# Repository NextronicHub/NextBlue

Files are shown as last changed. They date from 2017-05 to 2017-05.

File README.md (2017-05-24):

# Nextronic NextBlue

With nextBlue, your Iot and Bluetooth applications are  easier to make
it's a 5v 16Mhz board based on the ATmega328P microcontroller with a built-in Bluetooth connector
NextBlue can be programmed over a USB Mini-B cable using the Arduino IDE: Just plug in the board, select “Arduino UNO” from the board menu and you’re ready to upload code.
NextBlue has all of the hardware peripherals like the Arduino.

## Features

  ATmega328 microcontroller with Optiboot (UNO) Bootloader<br />
  Input voltage - 7-15V<br />
  0-5V outputs<br />
  14 Digital I/O Pins (6 PWM outputs)<br />
  6 Analog Inputs<br />
  I2C, UART and SPI<br />
  32k Flash Memory<br />
  16MHz Clock Speed<br />
  All SMD Construction<br />
  R3 Shield Compatible<br />
  Bluetooth connector (EN, 5V, GND, TX, RX, STATE) <br />
  Software/hardware serial selector switch for the Bluetooth<br />

<br />
<br />
[FTDI driver](http://www.ftdichip.com/Drivers/VCP.htm)

Nextronic Product page:[NextBlue](http://nextronic.ma/product/nextblue/).

you can by it at: [makershop.ma](http://makershop.ma/).

## Repository Contents

/Hardware - Design files (.brd, .sch)  
/Firmware - bootloader  
/Documentation - datasheet and examples

## Product Versions

NextBlue_V1 first release

## License Information

The hardware is released under [Creative Commons ShareAlike 4.0 International](https://creativecommons.org/licenses/by-sa/4.0/).

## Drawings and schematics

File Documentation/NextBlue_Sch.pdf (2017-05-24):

# GND 0.1uF

# LED3 J5

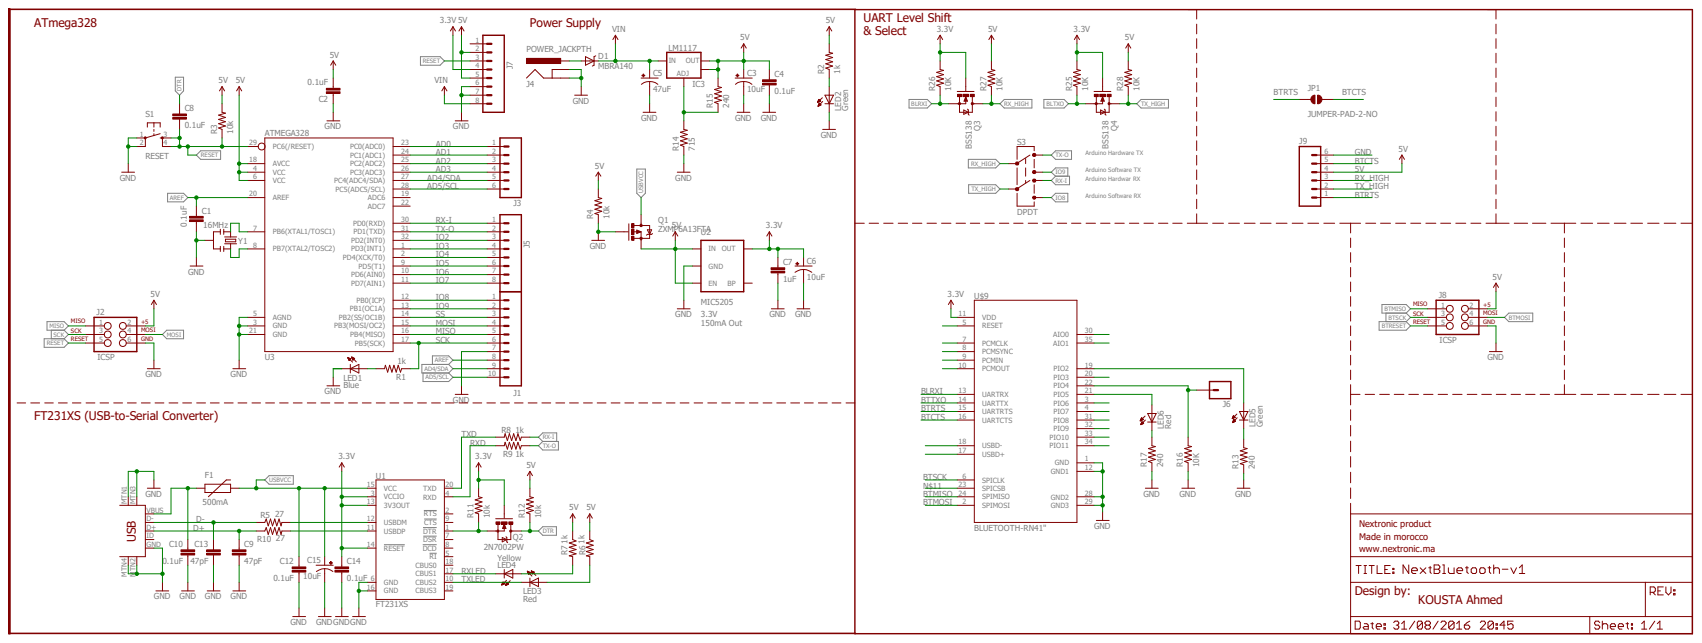
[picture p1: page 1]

FT231XS (USB-to-Serial Converter)

ID MTN¹ MTN³ MTN⁴ MTN²
GND

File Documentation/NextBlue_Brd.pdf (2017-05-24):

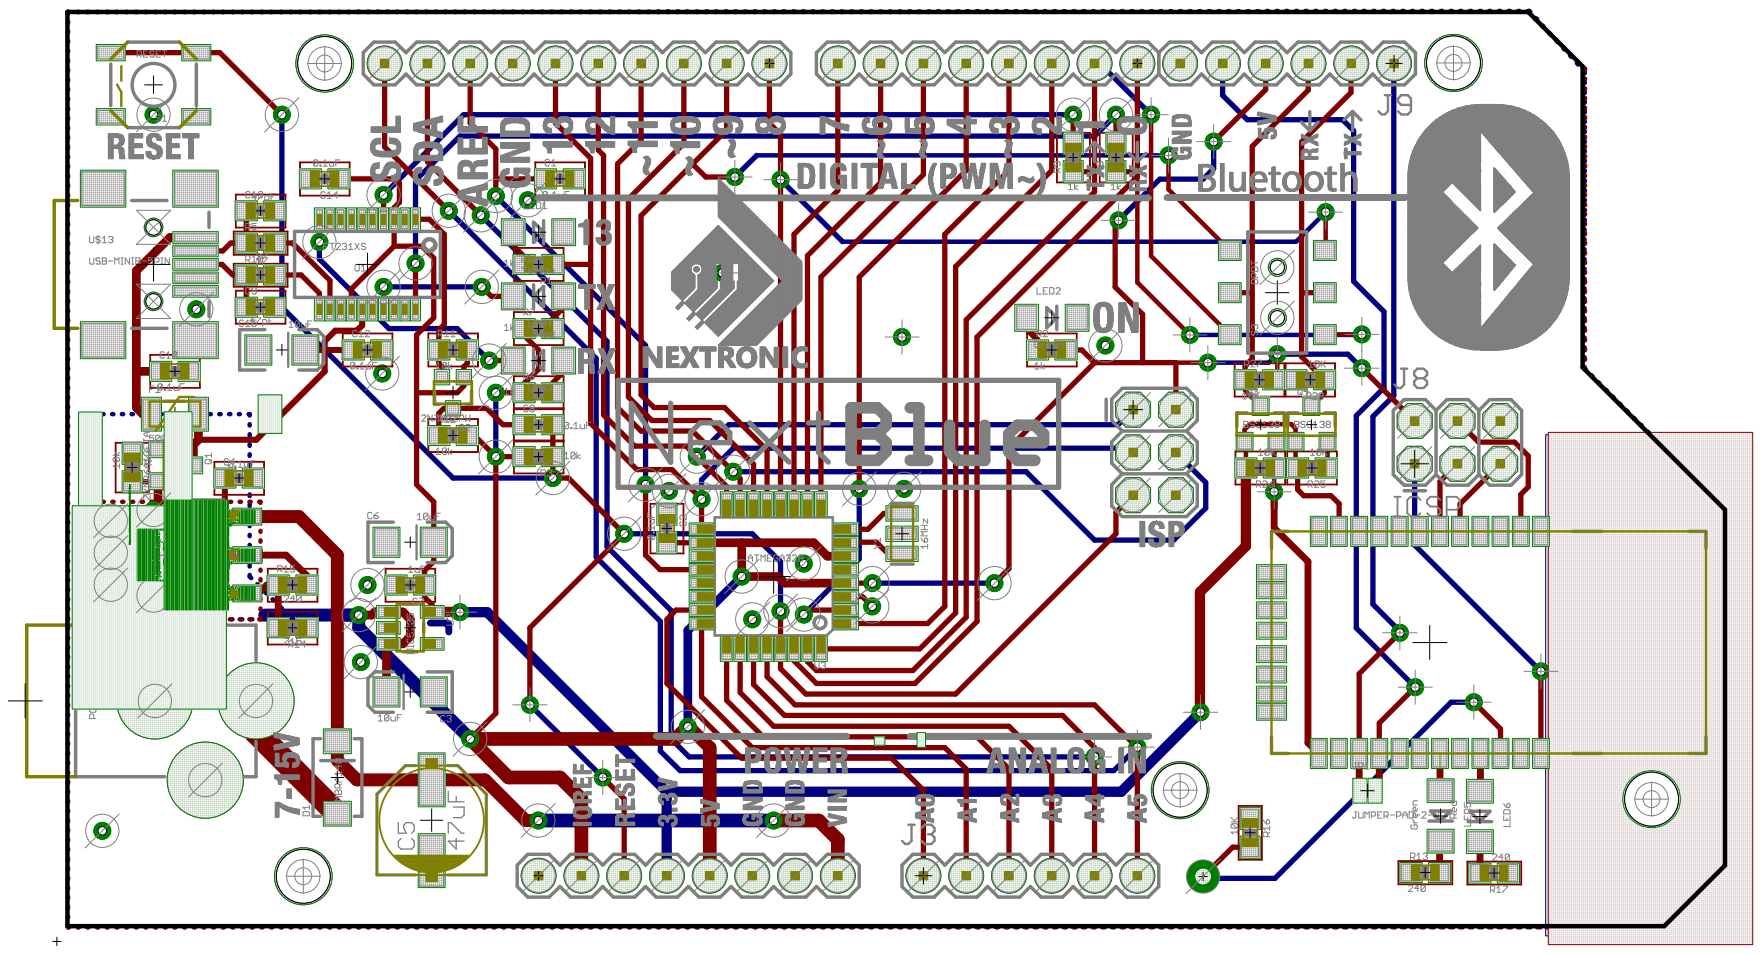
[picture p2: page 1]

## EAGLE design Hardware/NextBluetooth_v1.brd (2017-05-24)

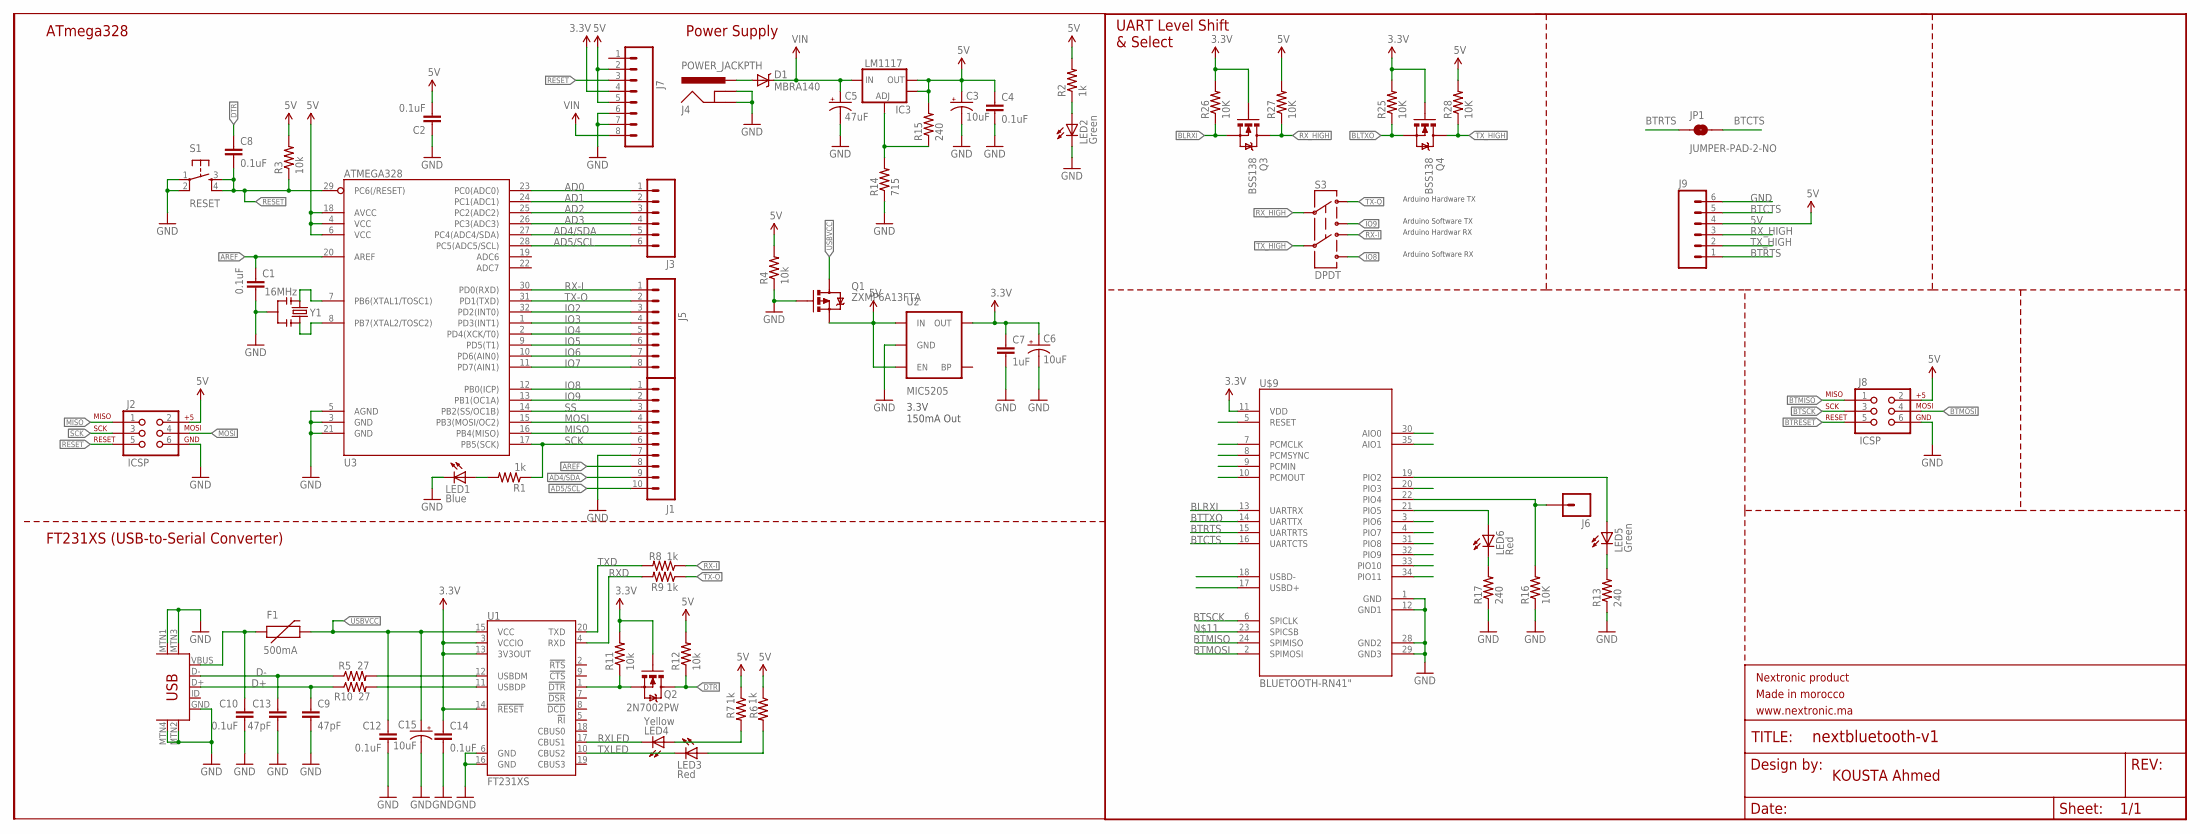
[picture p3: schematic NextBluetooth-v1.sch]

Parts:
C1, C2, C4, C8, C10, C12, C14: 0.1uF; 0603-CAP; MPN 0805B104K500CT
C3, C6, C15: 10uF; EIA3216; MPN MCSH21B104K101CT
C5: 47uF; PANASONIC_D; MPN EEEFT1H470AP
C7: 1uF; 0603-CAP; MPN ECA2GHG2R2
C9, C13: 47pF; 0603-CAP@1; MPN 08051A470JAT2A
D1: MBRA140; SMA-DIODE; MPN B140-13-F
F1: 500mA; PTC-1206; MPN 1N4148.
FRAME1: FRAME-LETTER; CREATIVE_COMMONS
IC3: LM1117; SOT223-ALT1; MPN LD1117S33TR
J1: M10SILK_FEMALE_PTH; 1X10
J2, J8: ICSP; 2X3
J3, J9: M06SILK_FEMALE_PTH; 1X06
J4: POWER_JACKPTH; POWER_JACK_PTH
J5, J7: M08; 1X08_ROUND
J6: M01NOSILK-KIT; 1X01NS-KIT
JP1: JUMPER-PAD-2-NO; PAD-JUMPER-2-NO_NO_SILK
LED1: Blue; LED-1206-NO_SILK; MPN 703-1028
LED2, LED5: Green; LED-1206-NO_SILK; MPN 703-1028
LED3, LED6: Red; LED-1206-NO_SILK; MPN 703-1028
LED4: Yellow; LED-1206-NO_SILK; MPN TLUY2401
Q1: ZXMP6A13FTA; SOT23-3; MPN ZXMP6A13FTA
Q2: 2N7002PW; SOT323; MPN 2N7002PW
Q3, Q4: BSS138; SOT23-3; MPN BSS138PW
R1, R2, R6, R7, R8, R9: 1k; 0603-RES; MPN ERA6AEB102V
R3, R4, R11, R12: 10k; 0603-RES; MPN MC0063W0603510K
R5, R10: 27; 0603-RES; MPN 22-27-2021
R13, R15, R17: 240; 0603-RES; MPN MCMR06X2200FTL
R14: 715; 0603-RES; MPN RC0603JR-07150RL
R16: 10K; 0603-RES; MPN RR0816P-103-B-T5
R25, R26, R27, R28: 10K; 0603-RES@2; MPN RR0816P-103-B-T5
S1: RESET; TACTILE_SWITCH_SMD
S3: DPDT; AYZ0202
U1: FT231XS; SSOP20_L; MPN FT231XS
U2: MIC5205; SOT23-5; MPN MIC5205-5.0YM5 TR
U3: ATMEGA328; TQFP32-08; MPN ATMEGA328P-AN
U$9: BLUETOOTH-RN41"; RN41
U$13: USB-MINIB-5PIN; USB-MINIB
Y1: 16MHz; RESONATOR-SMD

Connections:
3.3V: C6.A (+), C7.1, C14.1, J7.4, Q2.1 (G), Q3.1 (G), Q4.1 (G), R11.2, R25.2, R26.2, U1.3 (VCCIO), U1.13 (3V3OUT), U1.14 (!RESET), U2.5 (OUT), U$9.11 (VDD)
5V: C2.2, C3.A (+), C4.1, IC3.2 (OUT), IC3.4 (OUT), J2.2, J7.2, J7.5, J8.2, J9.4, Q1.2 (S), R2.2, R3.2, R4.2, R6.1, R7.1, R12.2, R15.2, R27.2, R28.2, U2.1 (IN), U2.3 (EN), U3.4 (VCC), U3.6 (VCC), U3.18 (AVCC)
AD0: J3.1, U3.23 (PC0(ADC0))
AD1: J3.2, U3.24 (PC1(ADC1))
AD2: J3.3, U3.25 (PC2(ADC2))
AD3: J3.4, U3.26 (PC3(ADC3))
AD4/SDA: J1.9, J3.5, U3.27 (PC4(ADC4/SDA))
AD5/SCL: J1.10, J3.6, U3.28 (PC5(ADC5/SCL))
AREF: C1.1, J1.8, U3.20 (AREF)
BLRXI: Q3.2 (S), R26.1, U$9.13 (UARTRX)
BLTXO: Q4.2 (S), R25.1
BTCTS: J9.5, JP1.2, U$9.16 (UARTCTS)
BTMISO: J8.1, U$9.24 (SPIMISO)
BTMOSI: J8.4, U$9.2 (SPIMOSI)
BTRESET: J8.5, U$9.5 (RESET)
BTRTS: J9.1, JP1.1, U$9.15 (UARTRTS)
BTSCK: J8.3, U$9.6 (SPICLK)
BTTXO: U$9.14 (UARTTX)
D+: C9.1, R10.1, U$13.D+
D-: C13.1, R5.1, U$13.D-
DTR: C8.1, Q2.3 (D), R12.1
GND: C1.2, C2.1, C3.C (-), C4.2, C5.-, C6.C (-), C7.2, C9.2, C10.2, C12.2, C13.2, C14.2, C15.C (-), J1.7, J2.6, J4.GND, J4.GNDBREAK, J7.6, J7.7, J8.6, J9.6, LED1.C, LED2.C, Q1.1 (G), R4.1, R13.1, R14.1, R16.1, R17.1, S1.1, S1.2, U1.6 (GND), U1.16 (GND), U2.2 (GND), U3.3 (GND), U3.5 (AGND), U3.21 (GND), U$9.1 (GND), U$9.12 (GND1), U$9.28 (GND2), U$9.29 (GND3), U$13.GND, U$13.MTN1 (MTN2), U$13.MTN2 (MTN3), U$13.MTN3 (MTN1), U$13.MTN4, Y1.2
IO2: J5.3, U3.32 (PD2(INT0))
IO3: J5.4, U3.1 (PD3(INT1))
IO4: J5.5, U3.2 (PD4(XCK/T0))
IO5: J5.6, U3.9 (PD5(T1))
IO6: J5.7, U3.10 (PD6(AIN0))
IO7: J5.8, U3.11 (PD7(AIN1))
IO8: J1.1, S3.6, U3.12 (PB0(ICP))
IO9: J1.2, S3.3, U3.13 (PB1(OC1A))
MISO: J1.5, J2.1, U3.16 (PB4(MISO))
MOSI: J1.4, J2.4, U3.15 (PB3(MOSI/OC2))
unnamed: LED1.A, R1.2
unnamed: LED2.A, R2.1
unnamed: U3.7 (PB6(XTAL1/TOSC1)), Y1.1
unnamed: U3.8 (PB7(XTAL2/TOSC2)), Y1.3
unnamed: D1.A, J4.PWR
unnamed: R5.2, U1.12 (USBDM)
unnamed: R10.2, U1.11 (USBDP)
unnamed: LED3.A, R6.2
unnamed: LED4.A, R7.2
unnamed: Q2.2 (S), R11.1, U1.1 (!DTR)
unnamed: IC3.1 (ADJ), R14.2, R15.1
unnamed: LED6.A, U$9.21 (PIO5)
unnamed: J6.1, R16.2, U$9.22 (PIO4)
unnamed: LED5.A, U$9.19 (PIO2)
unnamed: LED5.C, R13.2
unnamed: LED6.C, R17.2
RESET: C8.2, J2.5, J7.3, R3.1, S1.3, S1.4, U3.29 (PC6(/RESET))
RX-I: J5.1, R8.1, S3.4, U3.30 (PD0(RXD))
RXD: R9.2, U1.4 (RXD)
RXLED: LED4.C, U1.17 (CBUS1)
RX_HIGH: J9.3, Q3.3 (D), R27.1, S3.2
SCK: J1.6, J2.3, R1.1, U3.17 (PB5(SCK))
SS: J1.3, U3.14 (PB2(SS/OC1B))
TX-O: J5.2, R9.1, S3.1, U3.31 (PD1(TXD))
TXD: R8.2, U1.20 (TXD)
TXLED: LED3.C, U1.10 (CBUS2)
TX_HIGH: J9.2, Q4.3 (D), R28.1, S3.5
USBVCC: C12.1, C15.A (+), F1.2, Q1.3 (D), U1.15 (VCC)
VIN: C5.+, D1.C, IC3.3 (IN), J7.8
VUSB: C10.1, F1.1, U$13.VBUS

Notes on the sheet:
Power Supply
ATmega328
FT231XS (USB-to-Serial Converter)
3.3V 150mA Out
KOUSTA Ahmed
UART Level Shift & Select
Arduino Software TX
Arduino Software RX
Arduino Hardwar RX
Arduino Hardware TX

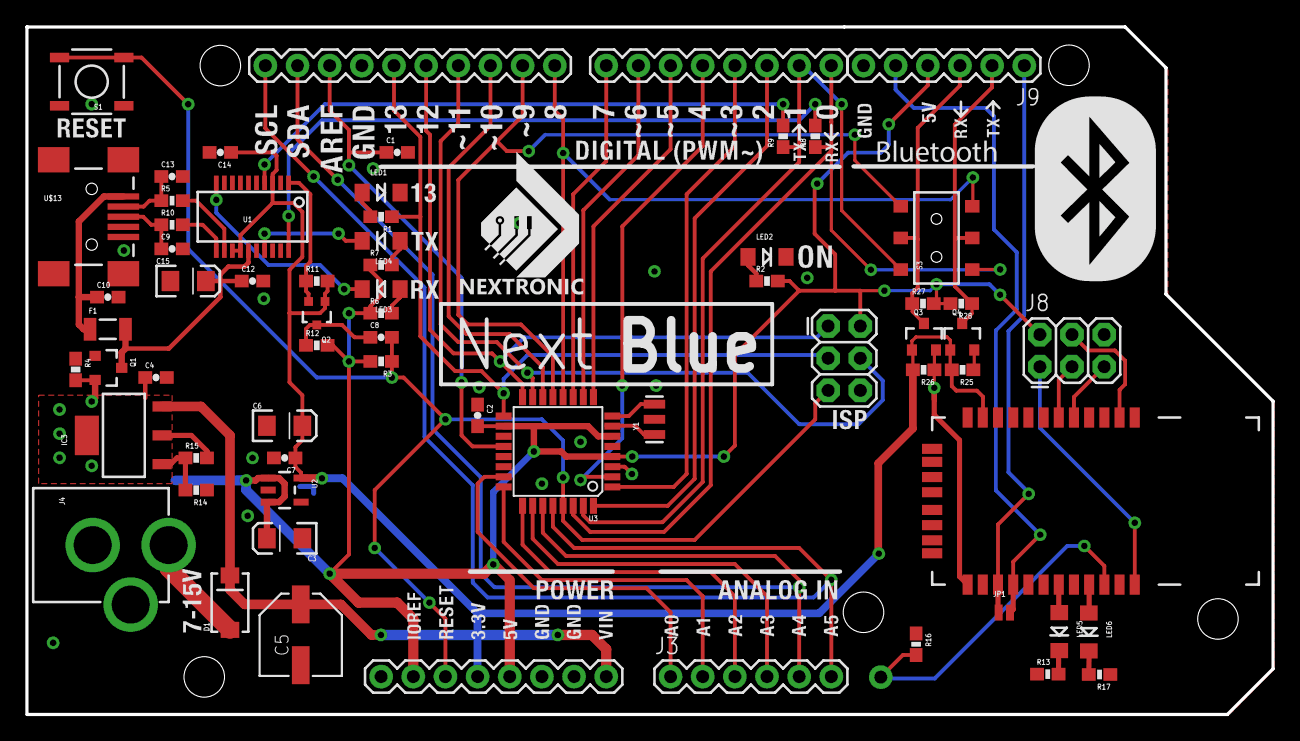
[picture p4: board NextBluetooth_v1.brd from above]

Board: 2 copper layers, 98.4 x 54.3 mm, 67 parts (0 on the bottom side), 61 nets.

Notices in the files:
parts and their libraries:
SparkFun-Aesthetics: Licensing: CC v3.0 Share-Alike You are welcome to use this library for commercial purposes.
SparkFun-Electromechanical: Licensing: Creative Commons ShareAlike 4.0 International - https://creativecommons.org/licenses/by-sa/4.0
